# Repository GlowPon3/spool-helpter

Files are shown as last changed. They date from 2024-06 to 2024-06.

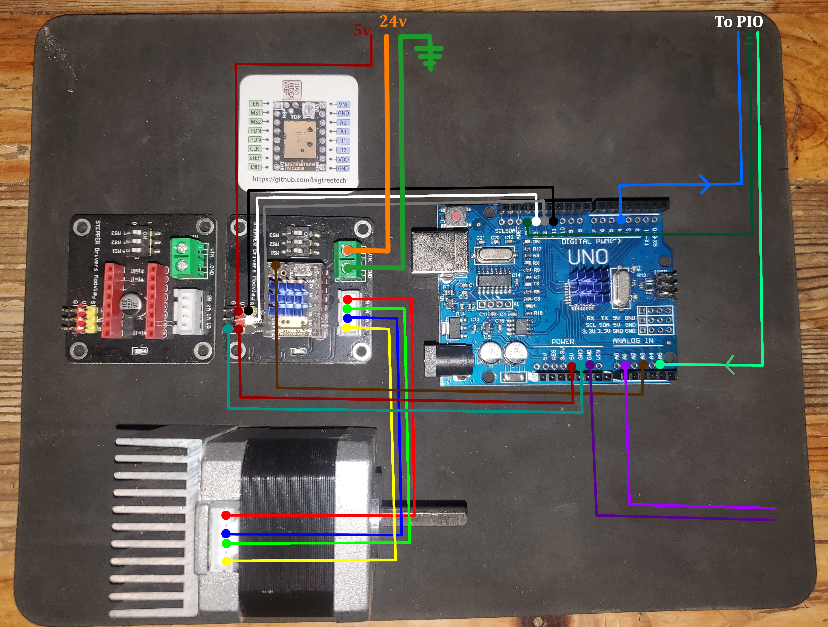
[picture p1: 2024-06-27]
Pinout-wired.jpg

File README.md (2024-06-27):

# spool-helpter
Arduino code for tension sensor and pre-feeder for 3d printers.
Used for TPU to prevent stretching and for 5K or larger spools to reduce strain on extruder.

Setup
See included arduino program and images for connections.
After printing, you will need to feed two wires through the bottom and connect to an arduino for sensing.  The code uses the build in pull-up resistor and a ground wire.
Make sure to use a metal washer so it will make contact with both wires.
Included are stls with single and no-hole options for adjusting yourself.

Why?
This was made originally to remove any tension from TPU because the resistance was changing the extrusion amount.  When I got a 5k spool I modified it to work with rigid filament as well.  5K spool is set on a lazy susan with a bolt holding it centered and a spacer with washers preventing it from sliding. I added a spring inline with the ptfe tube after the sensor to take up any overflow from the sensor/feeder setup.  The feeder is set to speed up fast and slow down gently, and it has been so gentle it has stopped the spool from springing at all.  Adjust the arduino code as needed if your feedrate is higher than mine.  

Adjust:
int minDelay = 200;  //minimum delay (fastest feedrate)
to a smaller number to get a higher max speed.  Note this is a delay between steps, so the smaller you go the speed increases non-linearly.

New program includes serial monitoring and control.  Baud 115200:
Send "help" or "?" to the serial line for a list of commands.

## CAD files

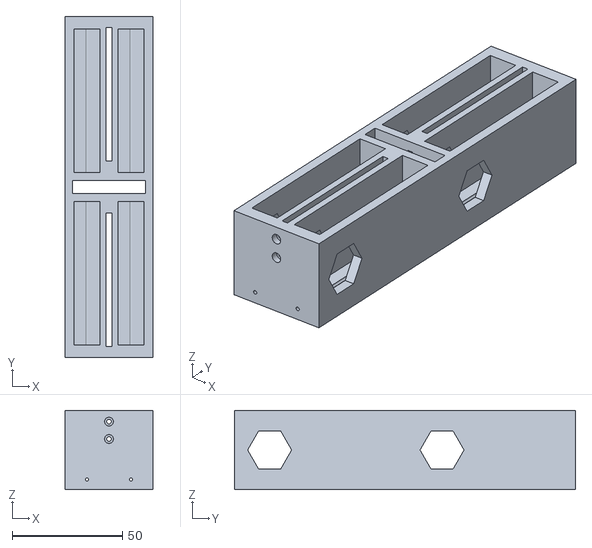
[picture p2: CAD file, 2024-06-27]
new tension sensor v2-tensionsensor-stl.stl
40.0 x 155.0 x 36.0

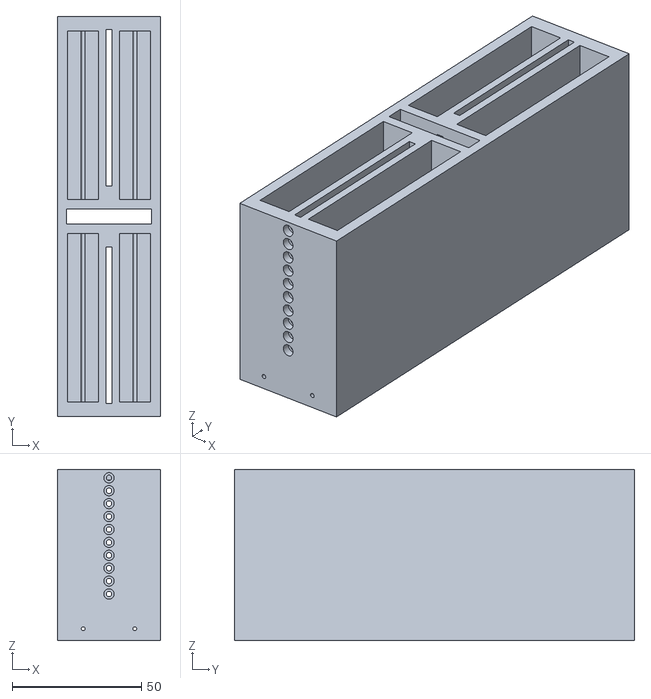
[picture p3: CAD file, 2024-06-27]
new tension sensor-all-holes.stl
40.0 x 155.0 x 66.2

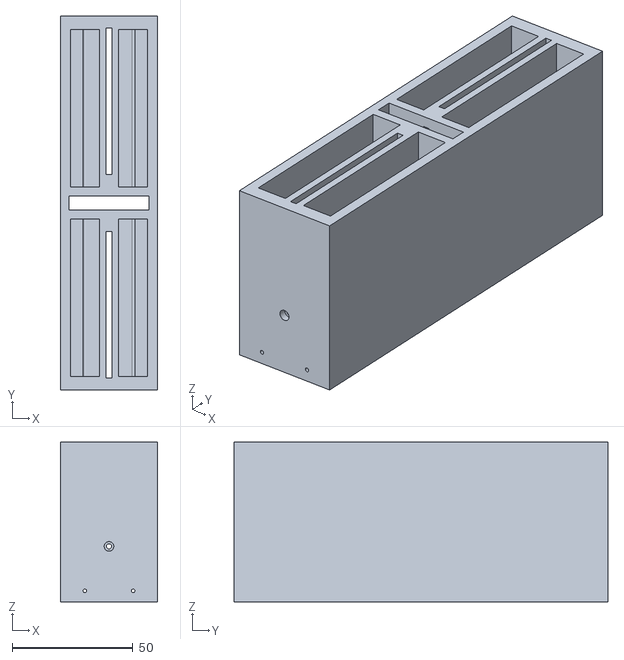
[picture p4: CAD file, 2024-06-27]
new tension sensor-single-hole.stl
40.0 x 155.0 x 66.2

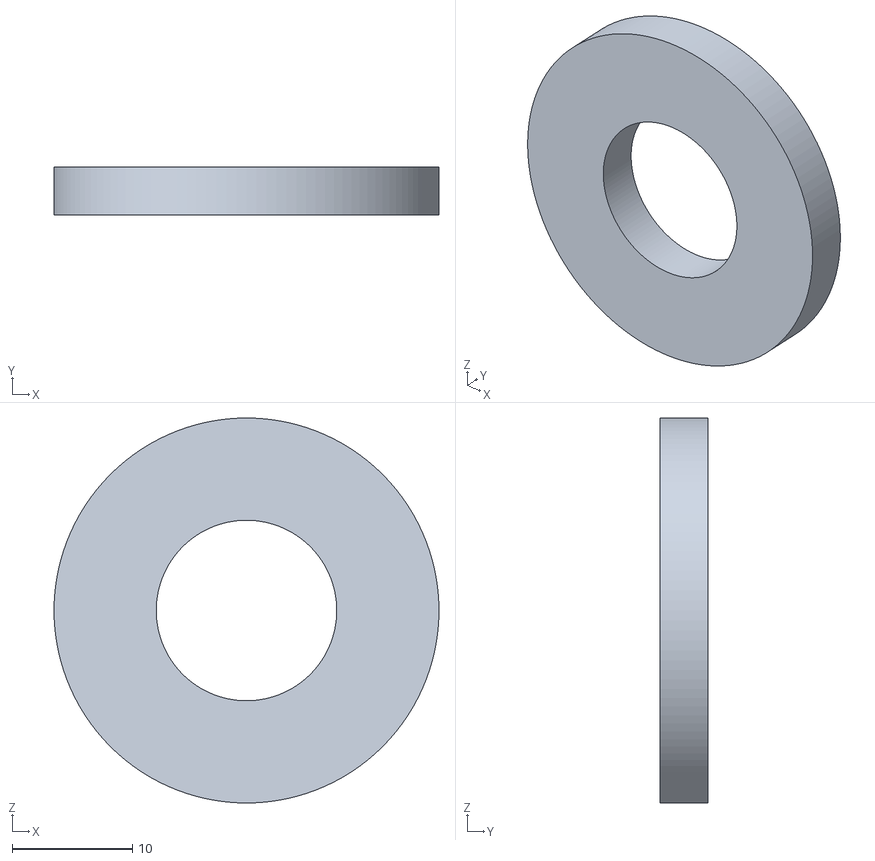
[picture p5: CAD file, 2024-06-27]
new tension sensor-washer.stl
32.0 x 4.00 x 32.0

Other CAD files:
new tension sensor-no-holes.stl

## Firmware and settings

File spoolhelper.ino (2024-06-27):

/*     Filament Tensioner for Arduino by Glowpon3 now for big spool
 *      
 *  11-6-2023   www.glowpon3.com
 *   5-27-2024 updated by Glowpon3
 *   6-26-2024 updated by Glowpon3 for serial control
 */

// defines pins numbers
int feedDebugPin = 4;  //output pin for SIO to show stepper activity
int stepPin = 13; //Output pin for stepper driver STEP pin
int dirPin = 12; //Output pin for stepper driver DIR pin
int enPin = 11;  //Output pin for stepper driver EN pin
int inputTensionLow = A1;  //Input pin for filament tension switch with integrated pull-up resistor enabled
int inputVref = A3; //Input pin for motor driver Vref pin for adjusting stepper current via serial debug
int inputSIO = A5;  //Input from SIO passed to stepper driver enable pin

int tensionLow;  //variable to store state of tension pin
int SIOenable;  //variable to store sio pin state
int vref1;  //variable to store vref pin value
float vref2;  //variable to store vref calculated as Volts

int delayStep = 1000;  //default speed when starting up
int minDelay = 200;  //minimum delay (fastest feedrate)
int maxDelay = 1000;  //maximum delay (slowest feedrate and idle trigger)

int p=10;  //used to speed up feedrate using equation delayStep -= (delaystep/p)
int i=2;  //depreciated
int d=10;  //used to slow down feedrate using equation delayStep += d
int j;  //for loop variable
int stepMode = 8;  //microstepping mode used in for loops

String oldAck = "";  //serial report handling
String newAck = "";  //serial report handling
int debugV = 0;  //for vref debug cleanup
int debugD = 0;  //for delay debug cleanup
int debugM = 0;  //for simple debug
bool flock = false;  //for manual control of enable pin
unsigned int stepRoll = 0;  //for debug output of distance travelled.
bool dir = true;  //for filament change and direction control


void setup() {
  pinMode(feedDebugPin,OUTPUT);
  pinMode(stepPin,OUTPUT); 
  pinMode(dirPin,OUTPUT);
  pinMode(enPin,OUTPUT);
  pinMode(inputTensionLow,INPUT_PULLUP);  //pullup resister enabled to make contact wiring easier
  pinMode(inputVref,INPUT);
  pinMode(inputSIO,INPUT);
  //start serial comms
  Serial.begin(115200);
}


void loop() {
  if(dir){
    digitalWrite(dirPin,HIGH); // makes sure motor is turning the correct way.  Change to LOW to reverse extruder gear direction
  } 
  else {
    digitalWrite(dirPin,LOW); // reverse direction flow if dir is false
  }

  //read tension pin
  tensionLow = digitalRead(inputTensionLow); //Read and store the sensor data
  
  //While input is high (not shorted to ground) accellerate to full speed
  while (tensionLow == 1) {
    checkSerial();
    checkEnable();
    tensionLow = digitalRead(inputTensionLow);  //read tension pin and update variable for while loop
    digitalWrite(feedDebugPin,HIGH);  //set debug pin high while stepping for output to SIO
    vref1 = analogRead(inputVref);  //test vref for serial debug
    vref2 = (debugV*(vref1/1024.)*5.);  //convert vref from int to voltage
 
    for (j=1;j<=stepMode;j++) {
      //for loop for duplicating steps for microstepping
      digitalWrite(stepPin,HIGH);  //output first step
      delayMicroseconds(delayStep);  //delay
      digitalWrite(stepPin,LOW);  //output second step
      delayMicroseconds(delayStep);  //delay
    }
    stepRoll += 1;  //increment distance tracker
    delayStep -= (delayStep/p);  //decrement delayStep by (delayStep / p) produces accelleration curve instead of linear
    if (delayStep < minDelay) {delayStep = minDelay;}  //make sure delayStep isn't below minDelay and correct if needed
    if(debugM){
      newAck = ("Delay " + String(delayStep*debugD) + "-Feeding " + String(vref2) + " Vref on? " + String(debugV) + " Distance " + String(stepRoll));
      ack();
    };
  }  //end while loop High

  //whiel tension is low, slow stepper and then stop
  while (tensionLow == 0) {
    checkSerial();
    checkEnable();
    tensionLow = digitalRead(inputTensionLow);  //read tension pin and update variable for while loop
    digitalWrite(feedDebugPin,LOW);  //set debug pin low while stepping
    vref1 = analogRead(inputVref);
    vref2 = (debugV*(vref1/1024.)*5.);
    //if delay step is less than, most importantly not equal to, max delay, then slow down.
    if (delayStep < maxDelay) {
      for (j=1;j<=stepMode;j++) {
        digitalWrite(stepPin,HIGH);
        delayMicroseconds(delayStep);
        digitalWrite(stepPin,LOW);
        delayMicroseconds(delayStep);
      }  //for loop for duplicating steps for microstepping
      stepRoll += 1;  //increment distance tracker
    }  //end if loop for stopping extruder 
    delayStep += d;  //decrement delayStep by d
    if (delayStep > maxDelay) delayStep = maxDelay;  //make sure delayStep isn't above maxDelay and correct if needed
    if(debugM){
      if (delayStep == maxDelay){
        newAck = ("Delay " + String(delayStep*debugD) + "-Stopped " + String(vref2) + " Vref on? " + String(debugV) + " Distance " + String(stepRoll));
      } else {
        newAck = ("Delay " + String(delayStep*debugD) + "-Slowing " + String(vref2) + " Vref on? " + String(debugV) + " Distance " + String(stepRoll));
      };
      ack();
    };
  }  //end while loop Low

} //end of void loop

void ack() {
  if (oldAck != newAck) {
    Serial.println(newAck);
    oldAck = newAck;
    };  //if Acknowledgement has changed, report to serial and update oldAck
}

void checkEnable(){
  if (flock) {
    digitalWrite(enPin, LOW);  // Enable stepper driver board regardless of SIO input
  }
  else {
    SIOenable = digitalRead(inputSIO); //check the SIO pin to see if feeder should be enabled. use SIOenable = 1 if SIO is not connected
    if (SIOenable) {
      digitalWrite(enPin,LOW);  // Enables the stepper driver board
    }
    else {
      digitalWrite(enPin,HIGH);  // Disable the stepper driver board
    };
  };
}

void checkSerial(){
  if (Serial.available()){
    
    String buf = Serial.readStringUntil('\n');  //fetch the buffer until the first line break
    buf.trim();  //trim any leading or trailing whitespaces
    int sepPos = buf.indexOf(" ");
    String command ="";
    String value = "";

    if(sepPos !=-1){
      //if the index of a separator exists then calculate the command and the value after the separator
      command = buf.substring(0,sepPos);
      value = buf.substring(sepPos+1);
    }else{
      //if there is no separator then just use the buffer as the full command
      command = buf;
    }
    command.toLowerCase();  //convert command to Lower Case
    
    if(debugD || debugM){
      if(command != ""){
        debugD = 0;
        debugM = 0;
        Serial.println("Monitor halted, ready for command:");
      };
    };
    
    if(command.startsWith("?") || command == "help"){
      Serial.println(F("Help:"));
      Serial.println(F("Commands:"));
      Serial.println(F("m (monitor activity)"));
      Serial.println(F("Vout on/off (enable Vref output)"));
      Serial.println(F("Dout (enable Delay output)"));
      Serial.println(F("send any key to exit monitoring"));
      Serial.println(F("report (echo variables)"));
      Serial.println(F("Delay (impermanantly set delay)"));
      Serial.println(F("mind (set max speed)"));
      Serial.println(F("maxd (set min speed)"));
      Serial.println(F("P (controls accelleration d -= d/p)"));
      Serial.println(F("I (depreciated)"));
      Serial.println(F("D (controls decelleration d += d)"));
      Serial.println(F("flock on/off (locks enable pin on)"));
      Serial.println(F("count (reset steproll count)"));
      Serial.println(F("steps (set microstepping mode)"));
      Serial.println(F("! (emergency restore defaults with flock enabled)"));
      Serial.println(F("C (change direction)"));
    }
    else if(command == "vout"){
      if (value == "on" || value == "1") {
        debugV = 1;
        Serial.println("Vref debug on");
      }
      else if(value == "off" || value == "0"){
        debugV = 0;
        Serial.println("Vref debug off");
      }
      else {
        Serial.println("value not recognized, use on/off or 1/0");
      }
      return;
    } 
    else if(command == "dout"){ 
      debugD = 1;
      Serial.println("Delay debug on");
      return;
    } 
    else if(command == "m"){ 
      debugM = 1;
      Serial.println("monitor on");
      return;
    } 
    else if(command == "report"){ 

      Serial.println("delay----" + String(delayStep));
      Serial.println("mindelay-" + String(minDelay));
      Serial.println("maxdelay-" + String(maxDelay));
      Serial.println("p--------" + String(p));
      Serial.println("i--------" + String(i));
      Serial.println("d--------" + String(d));
      Serial.println("Flock----" + String(flock));
      Serial.println("Steps----" + String(stepRoll));
      Serial.println("MSteps---" + String(stepMode));
      return;
    } 
    else if(command == "delay"){ 
      delayStep = value.toInt();
      Serial.println("delay = " + String(delayStep));
      return;
    } 
    else if(command == "mind"){ 
      minDelay = value.toInt();
      Serial.println("mindelay = " + String(minDelay));
      return;
    } 
    else if(command == "maxd"){ 
      maxDelay = value.toInt();
      Serial.println("maxdelay = " + String(maxDelay));
      return;
    } 
    else if(command == "p"){ 
      p = value.toInt();
      Serial.println("P = " + String(p));
      return;
    } 
    else if(command == "i"){ 
      i = value.toInt();
      Serial.println("I = " + String(i));
      return;
    } 
    else if(command == "d"){ 
      d = value.toInt();
      Serial.println("D = " + String(d));
      return;
    } 
    else if(command == "flock"){ 
      if (value == "on" || value == "1") {
        flock = true;
        Serial.println("Feed-Lock ON");

      }
      else if(value == "off" || value == "0") {
        flock = false;
        Serial.println("Feed-Lock OFF");

      }
      else {
        Serial.println("value not recognized, use on/off or 1/0");
      }
      return;
    }
    else if(command == "count"){ 
      stepRoll = 0;
      Serial.println("Distance = " + String(stepRoll));
      return;
    }
    else if(command == "steps"){ 
      stepMode = value.toInt();
      Serial.println("Microstep mode = " + String(stepMode));
      return;
    }
    else if(command == "!"){ 
      delayStep = 1000;  //default speed when starting up
      minDelay = 200;  //minimum delay (fastest feedrate)
      maxDelay = 1000;  //maximum delay (slowest feedrate and idle trigger)
      p=10;  //used to speed up feedrate using equation delayStep -= (delaystep/p)
      i=2;  //depreciated
      d=10;  //used to slow down feedrate using equation delayStep += d
      stepMode = 8;  //microstepping mode used in for loops
      debugV = 0;  //for vref debug cleanup
      debugD = 0;  //for delay debug cleanup
      debugM = 0;  //for simple debug
      flock = true;  //for manual control of enable pin
      stepRoll = 0;  //for debug output of distance travelled.
      Serial.println("Emergency Defaults Restored!");
      return;
    }
    else if(command == "c"){ 
      if (value == "on" || value == "1") {
        dir = false;
        Serial.println("Direction Reversed");
      }
      else if(value == "off" || value == "0") {
        dir = true;
        Serial.println("Direction Forward");
      }
      else {
        Serial.println("value not recognized, use on/off or 1/0");
      }
      return;
    }
    else{
      Serial.print(F("ERR: bad cmnd["));Serial.print(command);Serial.println(F("]"));
    }
  }
}

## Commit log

2024-06-27 Added image references and stls
    uploading stls and image references
    [new tension sensor-all-holes.stl, new tension sensor-no-holes.stl, new tension sensor-single-hole.stl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]
2024-06-27 Add files via upload
    new slim version of sensor.
    [new tension sensor v2-tensionsensor-stl.stl]
